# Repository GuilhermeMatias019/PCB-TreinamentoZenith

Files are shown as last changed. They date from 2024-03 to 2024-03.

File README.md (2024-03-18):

# PCB-TreinamentoZenith

## Descrição do Projeto
<p align="center">Este é um projeto de uma placa de circuito impresso(PCB) para desenvolvimento e testes utilizando o microcontrolador STM32F103C8T6 utilizando o software KiCad 6.0.</p>

<a href="https://github.com/GuilhermeMatias019/PCB-TreinamentoZenith#-Perifericos-"><h2> Periféricos </h2></a>

-MPU6050 
-BMP280 
-LED RGB
-2 botões
-LDR
-Relé

-Botão de reset
-Conector micro USB
-Conector para Seial Wire Debug (SWD)
-Conector para seleção do modo de boot
-16 pinos de GPIO disponíveis

<p align = "center">
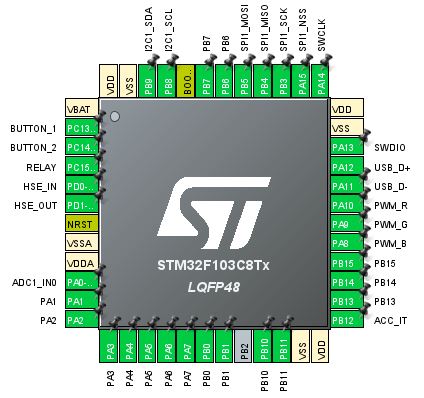
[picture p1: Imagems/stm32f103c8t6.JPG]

</p>
Configuração dos pinos do microcontrolador no STM32CubeMX.

<a href="https://github.com/GuilhermeMatias019/PCB-TreinamentoZenith#-Layout-"><h2> Layout </h2></a>

<p align = "center">
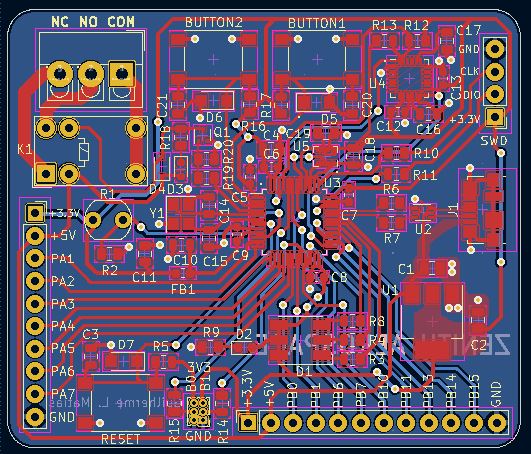
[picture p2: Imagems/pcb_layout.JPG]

</p>
Vista do layout da PCB.

<p align = "center">
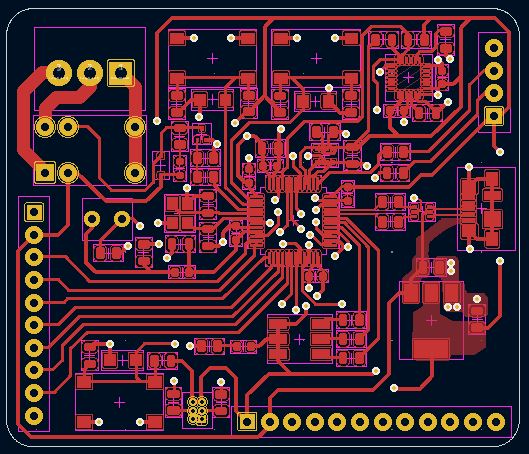
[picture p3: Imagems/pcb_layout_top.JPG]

</p>
Vista das trilhas na parte de cima da PCB.

<p align = "center">
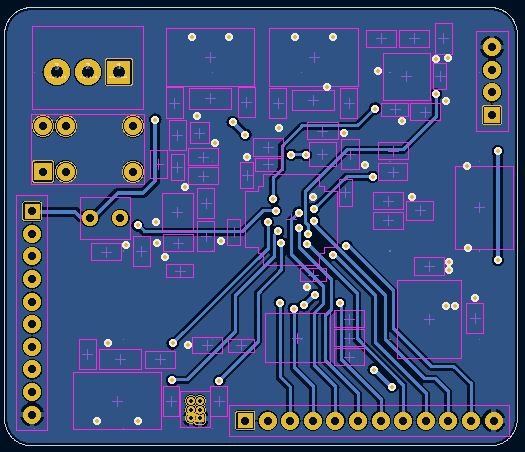
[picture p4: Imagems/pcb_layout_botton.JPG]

</p>
Vista das trilhas na parte de baixo da PCB.

<a href="https://github.com/GuilhermeMatias019/PCB-TreinamentoZenith#-3D-"><h2> Vista 3D </h2></a>

<p align = "center">
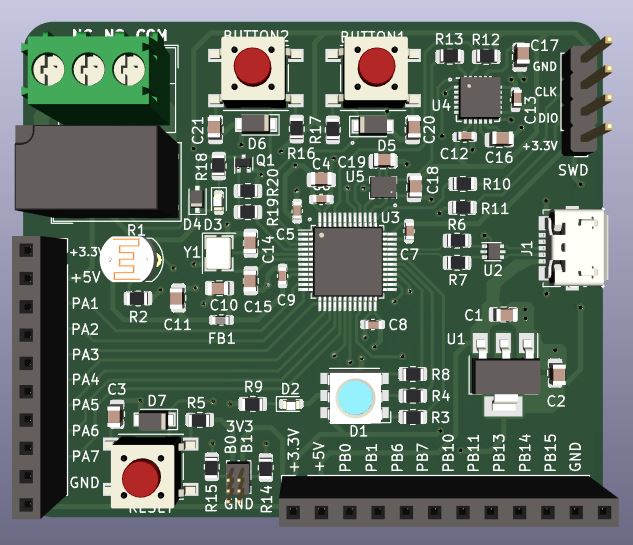
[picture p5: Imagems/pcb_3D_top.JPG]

</p>
Vista 3D da parte de cima da PCB.

<p align = "center">
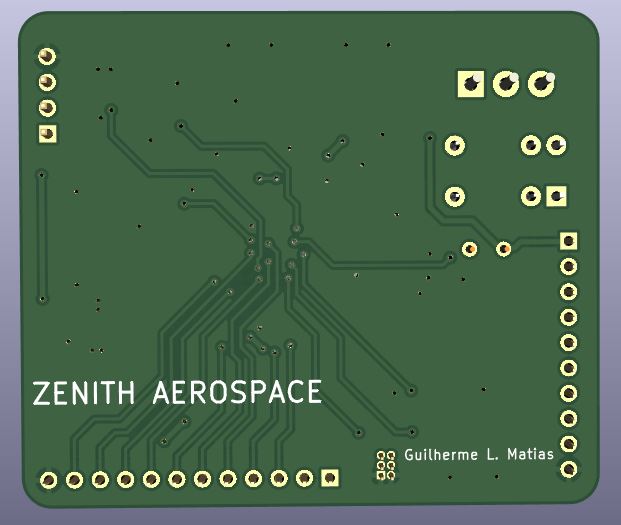
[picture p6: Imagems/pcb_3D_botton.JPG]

</p>
Vista 3D da parte de baixo da PCB.

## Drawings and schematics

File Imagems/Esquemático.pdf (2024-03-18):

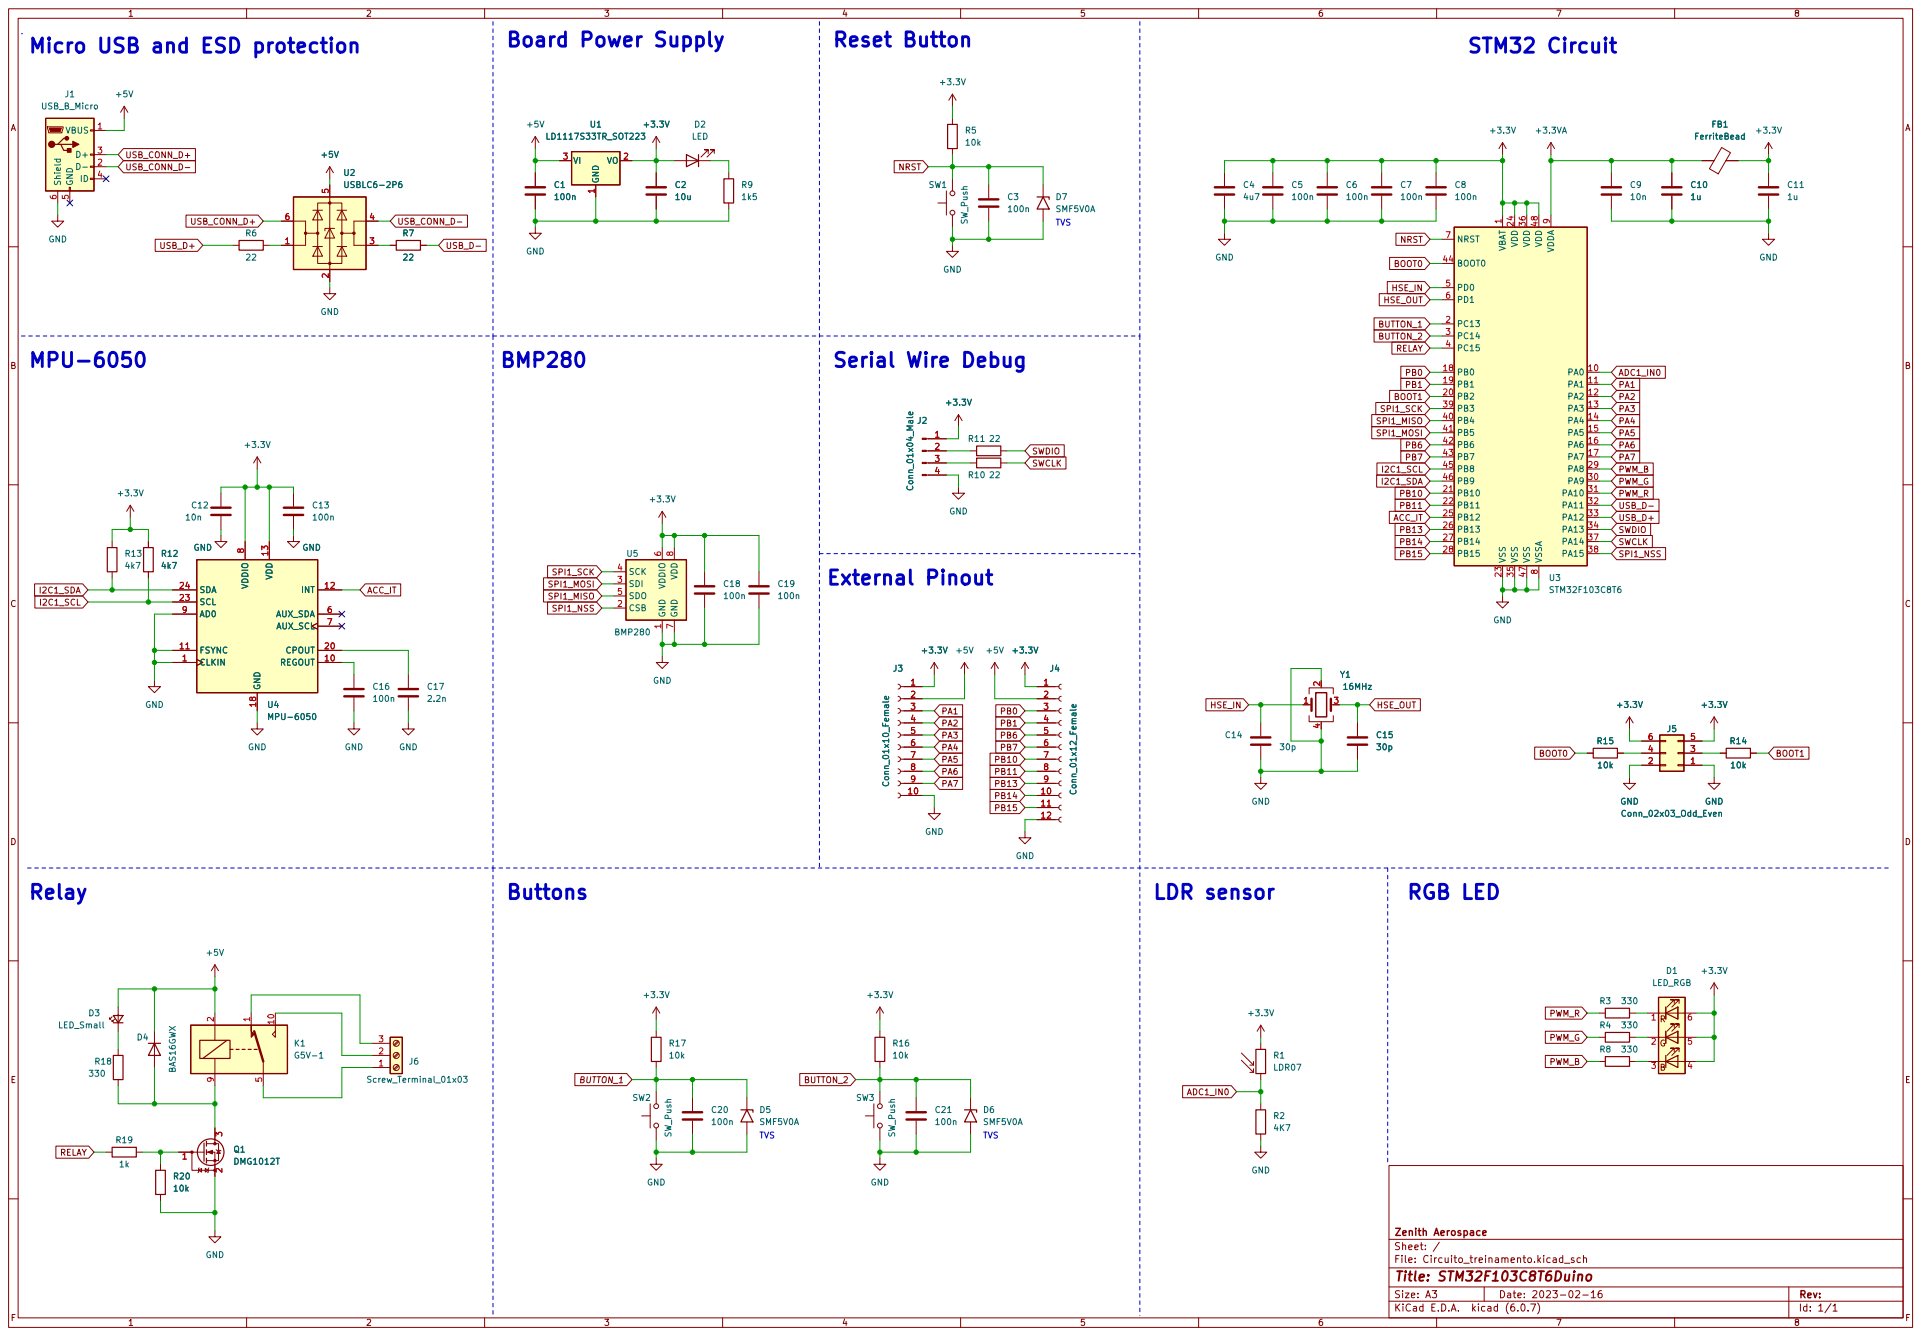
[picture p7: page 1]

1 PA0 10 PA1 11 PA2 12 PA3 13 PA4 14 PA5 15 PA6 16 PA7 17 PB0 18 PB1 19 PC13 2 PB2 20 PB10 21 PB11 22 VSS 23 VDD 24 PB12 25 PB13 26 PB14 27 PB15 28 PA8 29 PC14 3 PA9 30 PA10 31 PA11 32 PA12 33 PA13 34 VSS 35 VDD 36 PA14 37 PA15 38 PB3 39 PC15 4 PB4 40 PB5 41 PB6 42 PB7 43 BOOT0 44 PB8 45 PB9 46 VSS 47 VDD 48 PD0 5 PD1 6 NRST 7 VSSA

1 CSB 2 SDI 3 SCK 4 SDO 5 VDDIO

File: Circuito_treinamento.kicad_sch Sheet: / Zenith Aerospace

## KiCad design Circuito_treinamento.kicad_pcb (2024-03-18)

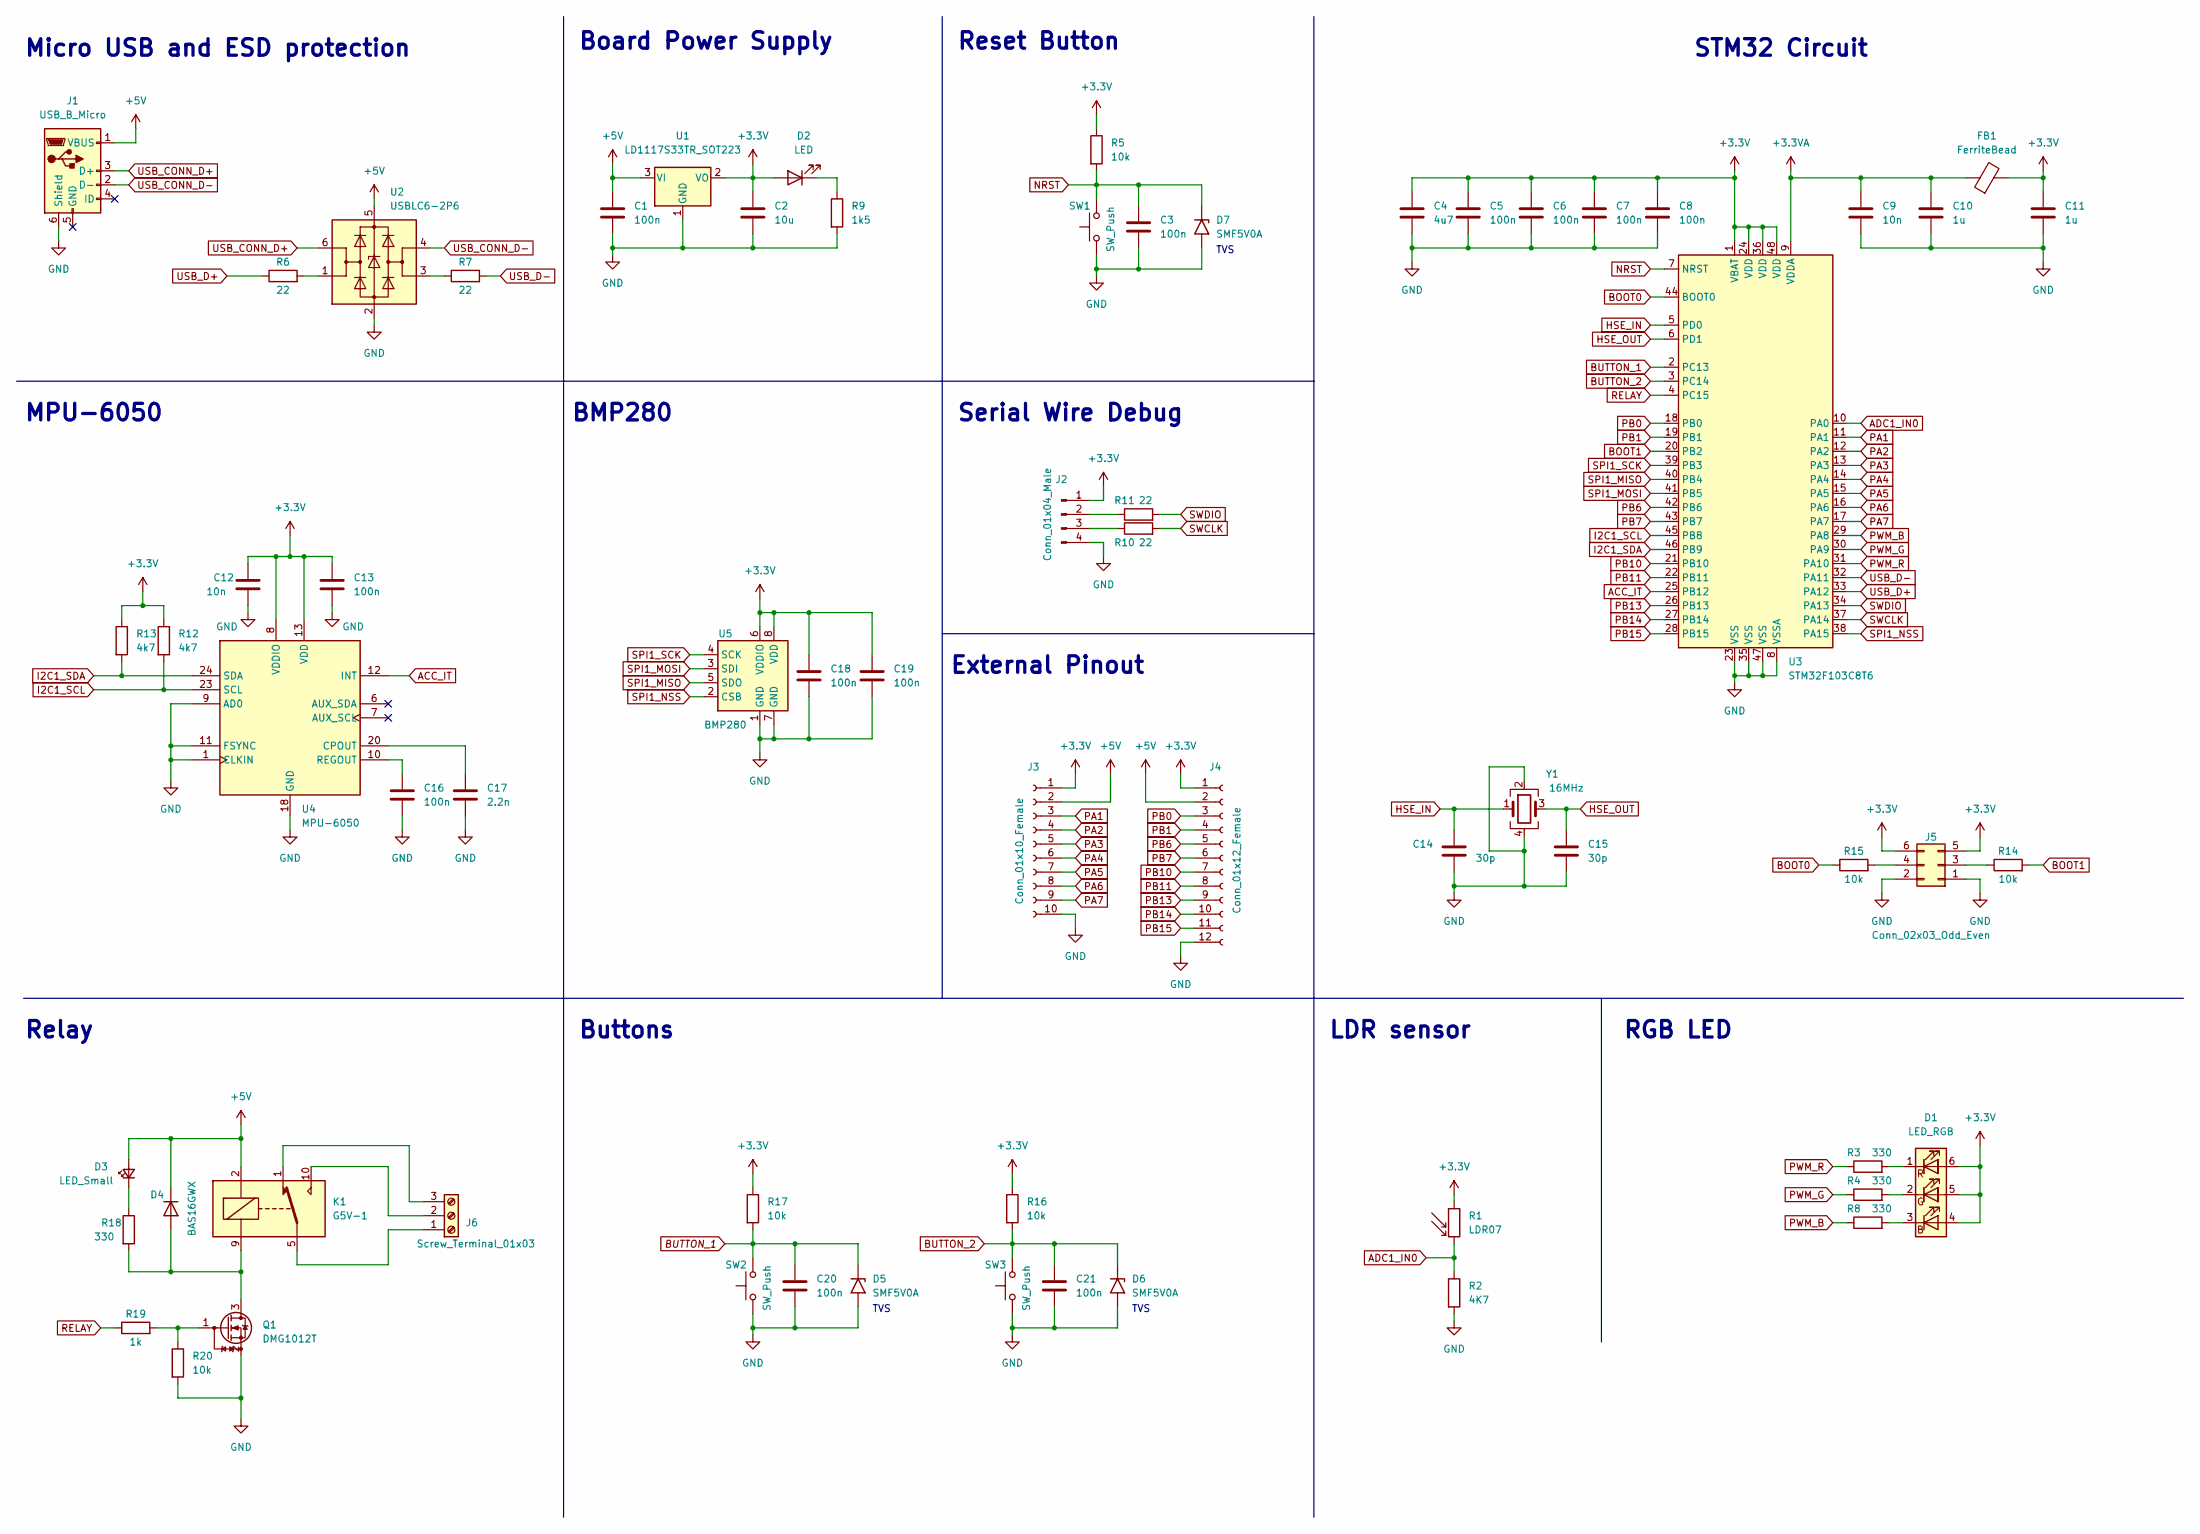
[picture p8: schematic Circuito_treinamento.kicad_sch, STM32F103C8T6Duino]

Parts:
C1, C3, C16, C18, C19, C20, C21: 100n; C_0805_2012Metric
C2: 10u; C_0805_2012Metric
C4: 4u7; C_0805_2012Metric
C5, C6, C7, C8, C13: 100n; C_0603_1608Metric
C9, C12: 10n; C_0603_1608Metric
C10, C11: 1u; C_0805_2012Metric
C14, C15: 30p; C_0805_2012Metric
C17: 2.2n; C_0805_2012Metric
D1: LED_RGB; LED_RGB_5050-6
D2: LED; LED_0603_1608Metric
D3: LED_Small; LED_0603_1608Metric
D4: BAS16GWX; D_SOD-323F
D5, D6, D7: SMF5V0A; D_SMF
FB1: FerriteBead; L_0603_1608Metric
J1: USB_B_Micro; USB_Micro-B_Molex_47346-0001
J2: Conn_01x04_Male; PinHeader_1x04_P2.54mm_Vertical
J3: Conn_01x10_Female; PinSocket_1x10_P2.54mm_Vertical
J4: Conn_01x12_Female; PinSocket_1x12_P2.54mm_Vertical
J5: Conn_02x03_Odd_Even; PinHeader_2x03_P1.00mm_Vertical
J6: Screw_Terminal_01x03; TerminalBlock_4Ucon_1x03_P3.50mm_Vertical
K1: G5V-1; Relay_SPDT_Omron_G5V-1
Q1: DMG1012T; SOT-523
R1: LDR07; R_LDR_5.1x4.3mm_P3.4mm_Vertical
R2: 4K7; R_0805_2012Metric
R3, R4, R8, R18: 330; R_0805_2012Metric
R5, R14, R15, R16, R17, R20: 10k; R_0805_2012Metric
R6, R7, R10, R11: 22; R_0805_2012Metric
R9: 1k5; R_0805_2012Metric
R12, R13: 4k7; R_0805_2012Metric
R19: 1k; R_0805_2012Metric
SW1, SW2, SW3: SW_Push; SW_Push_1P1T_NO_6x6mm_H9.5mm
U1: LD1117S33TR_SOT223; SOT-223-3_TabPin2
U2: USBLC6-2P6; SOT-666
U3: STM32F103C8T6; LQFP-48_7x7mm_P0.5mm
U4: MPU-6050; InvenSense_QFN-24_4x4mm_P0.5mm
U5: BMP280; Bosch_LGA-8_2x2.5mm_P0.65mm_ClockwisePinNumbering
Y1: 16MHz; Crystal_SMD_3225-4Pin_3.2x2.5mm

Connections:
+3.3V: C2.1, C4.1, C5.1, C6.1, C7.1, C8.1, C11.1, C12.1, C13.1, C18.1, C19.1, D1.4 (BA), D1.5 (GA), D1.6 (RA), D2.2 (A), FB1.2, J2.1, J3.1, J4.1, J5.5, J5.6, R1.1, R5.1, R12.1, R13.1, R16.1, R17.1, U1.2 (VO), U3.1 (VBAT), U3.24 (VDD), U3.36 (VDD), U3.48 (VDD), U4.8 (VDDIO), U4.13 (VDD), U5.6 (VDDIO), U5.8 (VDD)
+3.3VA: C9.1, C10.1, FB1.1, U3.9 (VDDA)
+5V: C1.1, D3.2 (A), D4.1 (K), J1.1 (VBUS), J3.2, J4.2, K1.2, U1.3 (VI), U2.5 (VBUS)
ACC_IT: U3.25 (PB12), U4.12 (INT)
ADC1_IN0: R1.2, R2.1, U3.10 (PA0)
BOOT0: R15.1, U3.44 (BOOT0)
BOOT1: R14.2, U3.20 (PB2)
BUTTON_1: C20.1, D5.1 (A1), R17.2, SW2.2, U3.2 (PC13)
BUTTON_2: C21.1, D6.1 (A1), R16.2, SW3.2, U3.3 (PC14)
GND: C1.2, C2.2, C3.2, C4.2, C5.2, C6.2, C7.2, C8.2, C9.2, C10.2, C11.2, C12.2, C13.2, C14.2, C15.2, C16.2, C17.2, C18.2, C19.2, C20.2, C21.2, D5.2 (A2), D6.2 (A2), D7.2 (A2), J1.6 (Shield), J2.4, J3.10, J4.12, J5.1, J5.2, Q1.2 (S), R2.2, R9.2, R20.2, SW1.1, SW2.1, SW3.1, U1.1 (GND), U2.2 (GND), U3.8 (VSSA), U3.23 (VSS), U3.35 (VSS), U3.47 (VSS), U4.1 (CLKIN), U4.9 (AD0), U4.11 (FSYNC), U4.18 (GND), U5.1 (GND), U5.7 (GND), Y1.2, Y1.4
HSE_IN: C14.1, U3.5 (PD0), Y1.1
HSE_OUT: C15.1, U3.6 (PD1), Y1.3
I2C1_SCL: R12.2, U3.45 (PB8), U4.23 (SCL)
I2C1_SDA: R13.2, U3.46 (PB9), U4.24 (SDA)
NRST: C3.1, D7.1 (A1), R5.2, SW1.2, U3.7 (NRST)
unnamed: C16.1, U4.10 (REGOUT)
unnamed: C17.1, U4.20 (CPOUT)
unnamed: D1.1 (RK), R3.2
unnamed: D1.2 (GK), R4.2
unnamed: D1.3 (BK), R8.2
unnamed: D2.1 (K), R9.1
unnamed: D3.1 (K), R18.1
unnamed: D4.2 (A), K1.9, Q1.3 (D), R18.2
unnamed: J2.2, R11.1
unnamed: J2.3, R10.1
unnamed: J5.3, R14.1
unnamed: J5.4, R15.2
unnamed: J6.1, K1.5, K1.6
unnamed: J6.2, K1.10
unnamed: J6.3, K1.1
unnamed: Q1.1 (G), R19.2, R20.1
unnamed: R6.2, U2.1 (I/O1)
unnamed: R7.1, U2.3 (I/O2)
PA1: J3.3, U3.11 (PA1)
PA2: J3.4, U3.12 (PA2)
PA3: J3.5, U3.13 (PA3)
PA4: J3.6, U3.14 (PA4)
PA5: J3.7, U3.15 (PA5)
PA6: J3.8, U3.16 (PA6)
PA7: J3.9, U3.17 (PA7)
PB0: J4.3, U3.18 (PB0)
PB1: J4.4, U3.19 (PB1)
PB6: J4.5, U3.42 (PB6)
PB7: J4.6, U3.43 (PB7)
PB10: J4.7, U3.21 (PB10)
PB11: J4.8, U3.22 (PB11)
PB13: J4.9, U3.26 (PB13)
PB14: J4.10, U3.27 (PB14)
PB15: J4.11, U3.28 (PB15)
PWM_B: R8.1, U3.29 (PA8)
PWM_G: R4.1, U3.30 (PA9)
PWM_R: R3.1, U3.31 (PA10)
RELAY: R19.1, U3.4 (PC15)
SPI1_MISO: U3.40 (PB4), U5.5 (SDO)
SPI1_MOSI: U3.41 (PB5), U5.3 (SDI)
SPI1_NSS: U3.38 (PA15), U5.2 (CSB)
SPI1_SCK: U3.39 (PB3), U5.4 (SCK)
SWCLK: R10.2, U3.37 (PA14)
SWDIO: R11.2, U3.34 (PA13)
USB_CONN_D+: J1.3 (D+), U2.6 (I/O1)
USB_CONN_D-: J1.2 (D-), U2.4 (I/O2)
USB_D+: R6.1, U3.33 (PA12)
USB_D-: R7.2, U3.32 (PA11)

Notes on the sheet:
TVS
Board Power Supply
Buttons
RGB LED
Relay
LDR sensor
BMP280
MPU-6050
STM32 Circuit
Reset Button
Micro USB and ESD protection
Serial Wire Debug
External Pinout

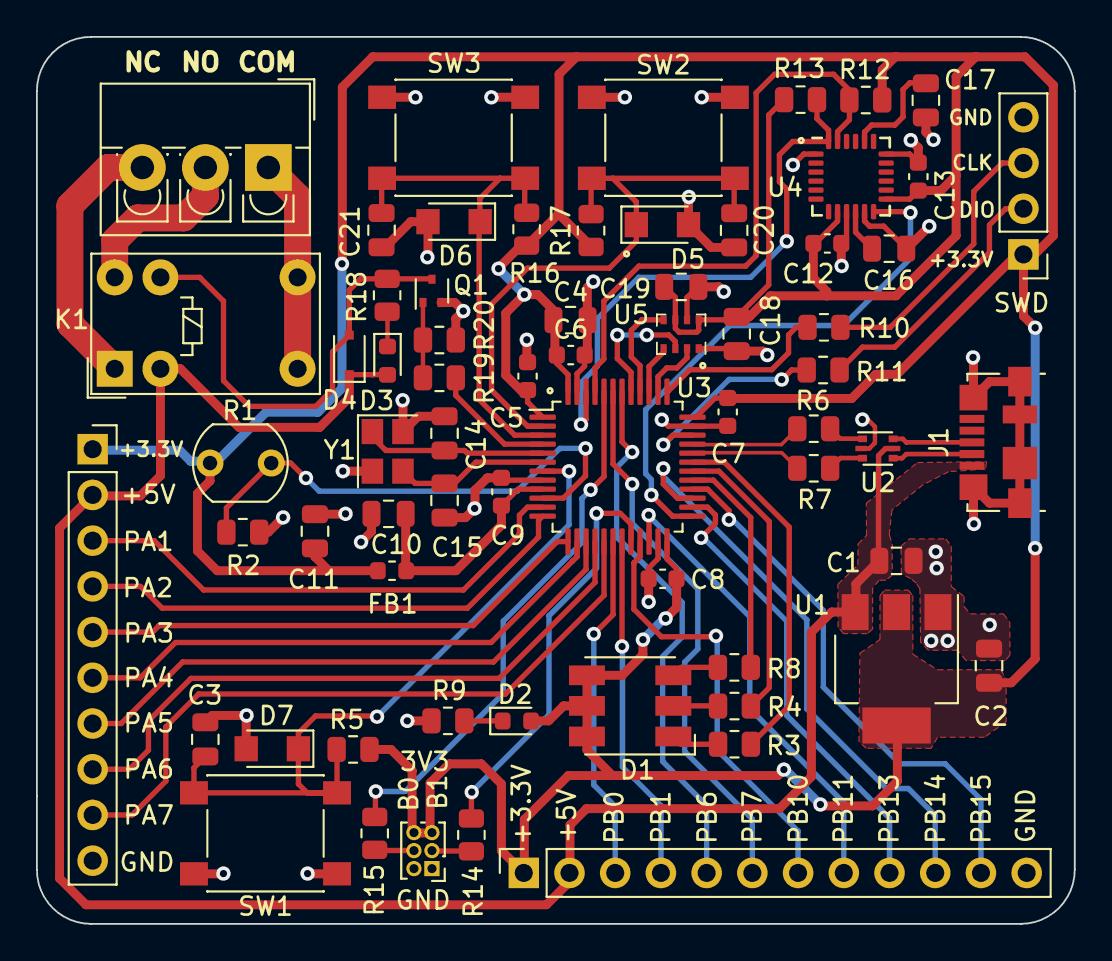
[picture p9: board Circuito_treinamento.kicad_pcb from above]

Board: 2 copper layers, 57.7 x 49.3 mm, 66 parts (0 on the bottom side), 63 nets.
